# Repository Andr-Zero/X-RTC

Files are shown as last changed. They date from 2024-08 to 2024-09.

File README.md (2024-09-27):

# X-RTC
A supplemental Real Time Clock for the Original Xbox 

The Original Xbox does not keep time when unplugged for an extended period of time. While some homebew apps have NTP functionality built in, not everyone plugs the console into their home network every time they play. 

Designed so the battery is only used when AC power is removed from the console. A CR2032 in theory should last 6-10 years when constantly being used. 
Should work with any modchip and TSOPed consoles. Have not tested with BFM BIOSes. 

SDA\SDL from the console are also brought to a set of solder pads for ease of installation of any other mod that may require them. 



# Board Specifications
0.8mm thick, castellated holes on all sides.

# 1.0-1.4 Installation
On the bottom of the Xbox motherboard. If you have a pinheader already installed, remove excessive solder from the pins outlined in purple and any that would interfere with the installation of the X-RTC QSB. Install the QSB onto the LPC port as shown above, make sure the QSB is sitting flush against the board. While keeping the QSB aligned, solder the QSB to the LPC port and the ground point outlined in black. Run a short wire from the console's 3.3v standby outlined in red to the 3v3 StdBy pad on the QSB. Lastly wire a 3v battery to the Positive and Negative solder pads on the QSB.



# 1.6 Installation
On the bottom of the Xbox motherboard. Remove any existing LPC rebuild QSB or wires that maybe installed. If a pinheader is already installed, remove solder from the bottom of the pinheader. No need to remove the pinheader, just enough for the X-RTC QSB can sit flush against the board. Solder the various LAD points first, then the ground connections around the QSB, solder the QSB to the LPC port and pinheader last. Make sure the solder is connecting to the QSB, pinheader, and the main board. All the edge points on the QSB need to contact the board. Since the 1.6 consoles have it’s standby voltage on the LPC, no need to run a wire like the early revisions. Last step is wiring a 3v battery to the Positive and Negative solder pads on the QSB. Your install should look like the 1.6 install at the top of this README

# BOM

| Part | Description | Digikey Link |
| --- | --- | --- |
| `0.1 uF` | Generic 0.1uF Ceramic Cap | https://www.digikey.com/short/408q3vwn |
| `DS3231MZ` | I2C Real Time Clock | https://www.digikey.com/short/m05dd78z |
| `XC6206P332MR` | 3.3v Regulator for 1.6 ONLY | https://www.digikey.com/short/bqdqftzn |

# Software
Cerbios 2.4.0 or higher is required to use X-RTC. 

> ; Enables Automatic Time Sync With Optional RTC Hardware Connected to SMBus
> 
> RtcEnable = True

Using a Chip that can use PrometheOS:
Version 1.4.0 or higher is able to set the time, enable RTC in PrometheOS Settings. (Rebooting recommended) 

TSOP or Other:
Download the X-RTC.xbe into your Apps folder, within you can set the time. 

Once the time is set and Cerbios is configured. The time on the console will set automatically on boot.

# License, Credits, & Thanks
The hardware and it's related files is licensed under CERN-OHL-S v2 or later version.
See License.txt, cern_ohl_s_v2.txt, and cern_ohl_s_v2_user_guide.txt for details.

1.6 LPC rebuild portion by Kekule. -> https://github.com/Kekule-OXC/OXC_LPCorrectr

Team Resurgent for the idea, PrometheOS, and the XBE.

Cerbios team for including functionality into their BIOS.

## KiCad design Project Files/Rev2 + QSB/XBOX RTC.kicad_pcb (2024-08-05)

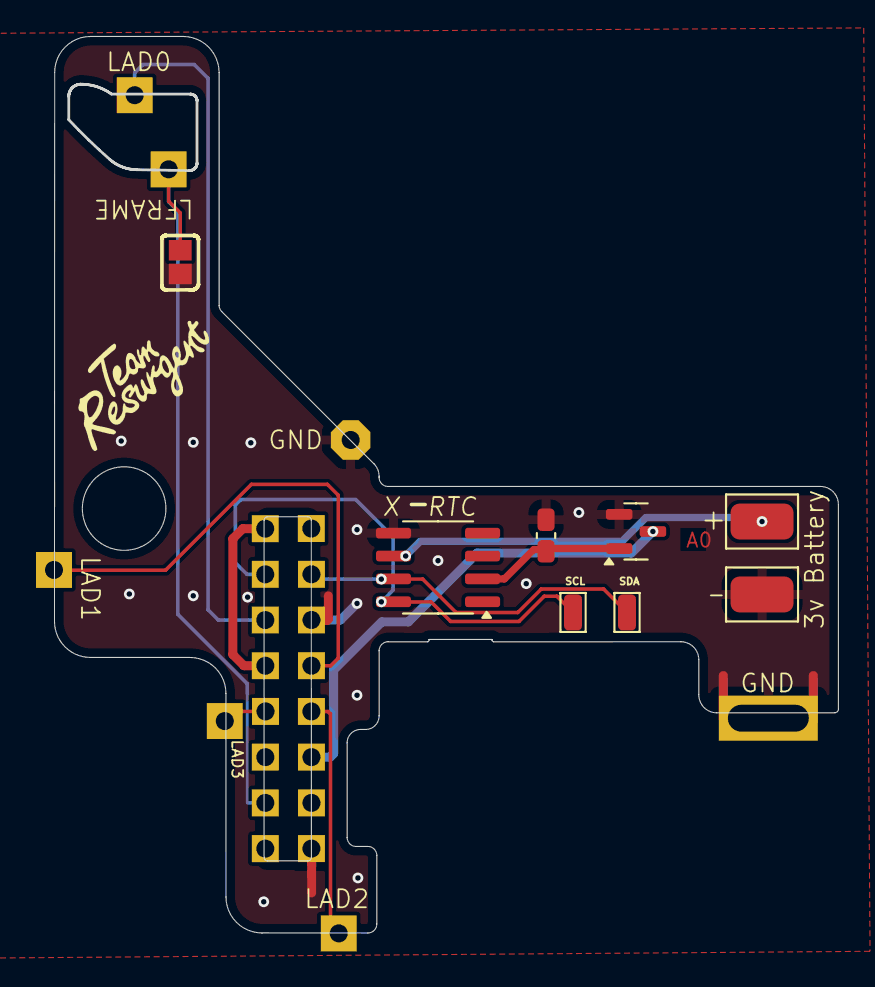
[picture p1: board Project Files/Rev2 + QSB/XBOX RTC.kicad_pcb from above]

Board: 2 copper layers, 43.6 x 49.8 mm, 7 parts (0 on the bottom side), 5 nets.

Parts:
C1: 0.1uF; C_0603_1608Metric
TP1: SCL; TestPoint_Pad_1.0x2.0mm
TP2: SDA; TestPoint_Pad_1.0x2.0mm
TP3: TestPoint; TestPoint_THTPad_2.5x2.5mm_Drill1.2mm
TP5: Batt +; TestPoint_Pad_1.0x2.0mm
TP6: Batt -; TestPoint_Pad_1.0x2.0mm
U1: DS3231MZ; SOIC-8_3.9x4.9mm_P1.27mm

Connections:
GND: C1.1, TP3.1, TP6.1, U1.5 (GND)
unnamed: TP1.1, U1.8 (SCL)
unnamed: TP2.1, U1.7 (SDA)
unnamed: TP5.1, U1.6 (VBAT)
unnamed: C1.2, U1.2 (VCC)

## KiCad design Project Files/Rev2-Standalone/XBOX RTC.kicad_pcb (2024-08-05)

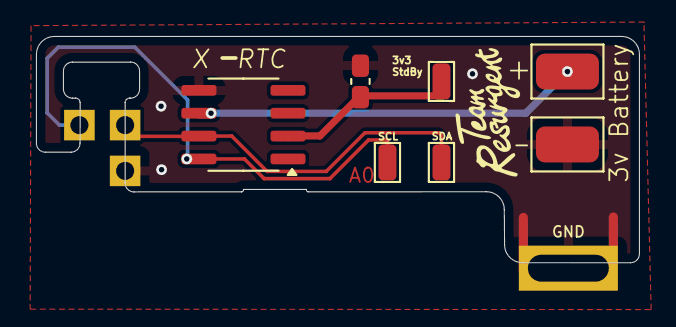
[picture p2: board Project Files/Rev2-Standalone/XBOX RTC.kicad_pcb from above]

Board: 2 copper layers, 33.5 x 12.6 mm, 9 parts (0 on the bottom side), 5 nets.

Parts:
C1: 0.1uF; C_0603_1608Metric
J3: Xbox LPC; PinSocket_2x08_P2.54mm_Vertical
TP1: SCL; TestPoint_Pad_1.0x2.0mm
TP2: SDA; TestPoint_Pad_1.0x2.0mm
TP3: TestPoint; TestPoint_THTPad_2.5x2.5mm_Drill1.2mm
TP4: 3v3 StdBy; TestPoint_Pad_1.0x2.0mm
TP5: Batt +; TestPoint_Pad_1.0x2.0mm
TP6: Batt -; TestPoint_Pad_1.0x2.0mm
U1: DS3231MZ; SOIC-8_3.9x4.9mm_P1.27mm

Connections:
GND: C1.1, J3.12, TP3.1, TP6.1, U1.5 (GND)
unnamed: J3.13, TP1.1, U1.8 (SCL)
unnamed: J3.14, TP2.1, U1.7 (SDA)
unnamed: TP5.1, U1.6 (VBAT)
unnamed: C1.2, TP4.1, U1.2 (VCC)

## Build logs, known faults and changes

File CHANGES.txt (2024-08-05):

July 28th 2024: Initial Release

August 4th 2024: Rerouted some traces for more continuous ground planes, increased LPC traces size to 0.2mm per feedback, removed mismatched silkscreen around ground points, moved the large GND pad .12mm as PCBWay suddenly had issues with it.

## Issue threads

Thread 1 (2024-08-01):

Add EDA design files

Redherring32, 2024-08-01:
The original self claimed intent of the OXC-LPCorrectr was to be open hardware.
Per the definition of open source the EDA software design files should be supplied. (E.g KiCad .kicad_pcb .kicad_sch and .kicad_pro files)
Gerber files are an output (they do not qualify for the definition of a source file, they're as close to source files as an EXE), and do not preserve the original documentation (schematic, editable layout, netlists, and net names) and therefore prevent anyone from contributing.

Admittedly the original project also doesn't properly do so either, but that doesn't stop this oversight from being corrected here. If you need any help with this just let me know.

Thanks.
-Red

MrMilenko, 2024-08-03:
When is MakeMHz going to release the KiCad files for the Xbox HD+ that they’ve been saying will be coming in the near future for the last 3 years?

Why is it that whenever someone outside of your group does anything, you guys flock to it with some kind of gotcha and make demands like this, but force pushing to fix two year old typos and releasing binary blobs as opensource is perfectly acceptable elsewhere?

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

hazardous774, 2024-08-03:
painschamp

Andr-Zero, 2024-08-05:
Alright... A couple musings, then I'm closing this.
1) To clarify the license, CERN-OHL-S v2 or later. The missing details in the readme and files needed to comply will be uploaded shortly with a revised gerbers, if not already.
2) One could argue comparing a gerber to a compiled executable is an error. They are indeed the source used for the production of a product. In a common format that most, if not all software can understand and import. In fact, this is how I imported Kekule's OXC-LPCorrectr into my project file. I often see other OSHW with only gerbers released.
3)Definition 1.8, " 'Complete Source' means the set of all Source necessary to Make a Product..." Since the PCB is a product, I see just the gerbers sufficient here.
4) In a partial contradiction of 3, yet partly affirming of 2 & 3. "...in the preferred form for making modifications..." What is “preferred”? Native EDA files? Well sure. For every EDA software out there? That seems silly… But that might be “preferred” by someone using a different EDA. Could just export as gerbers as that almost universal. Again, that’s how I imported the existing OXC-LPCorrectr design. However, that’s far from ideal for a much more complex design. I say “Preferred” is too ambiguous…
5) @MrMilenko, seeing that years ago is why I bought several in support of the designer. Seeing how nothing came from that I do feel taken advantage of, now regret that decision.

Regardless if my musings are accurate or not. It’s late at night and I really care either way. I will release the KiCAD files I have, I feel that is in the spirt of being Open Sourced. I think I took all the none related information out, like my grocery list from a few weeks ago… There are no schematics, as there was not a need for one. Otherwise I would include those as well. To the best of my current sleep deprived state, I believe I have all the necessary things in place for the OSHW license. If not, please contact my directly if you so feel.

Closed 2024-08-05.

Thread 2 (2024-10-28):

CR2032 situation

Radeon91, 2024-10-28:
Hi, could be possible to enlarge the pcb to add a holder for cr2032 or anotther small battery

Andr-Zero, 2024-10-30:
Question is where to put it. There isn't really much room where the board is now without worries hitting the IO Shield or other components on the main board across revisions. I did not want to top mount as I knew people likely already had a pinheader installed and removing it to install this did not make sense. Considered a seperate board elsewhere to hold a CR2032, then came the questions of where would people like it most and connecting the two. I knew despite what I came up with, someone somewhere was not going to like it. Plus it would also increase the price of materials, the RTC IC is already kinda expensive... Sooo, I decided to just do the solder pads instead to let people come up with their own solutions.

Some people sent me great pics of their installs! There's a Lillypad CR2032 holder that fits beside the IDE connector on the top side of the board, almost looks like it was made to go there, just held down with some foam tape. Saw someone use 18650s mounted above the AV port in a 3D printed bracket thingy. Someone else had a ton of CR2477 with tabs and used those instead.

Personally I'm going to get some Lillypad CR2032 holders and see how it looks mounted on the IO shield near the top. So if you ever had to replace the battery it's just right there. Though a standard CR2032 should expire from age before being drained from power consumption. So not sure how important that would be.

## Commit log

2024-07-31 Added App to set the time on the X-RTC board.
2024-08-05 Add files via upload
    Rerouted some traces to allow for better continuous ground planes, Increased the LPC traces to 0.2mm per some various feedback, removed mismatched silkscreens from ground points, added license on back silkscreen, PCBWay suddenly had issues with a tolerance on the large ground pad, so moved it 0.07mm to appease them.
2024-08-05 Add files via upload
    Initial upload of KiCAD files.
    [XBOX RTC.kicad_pcb]
2024-08-05 Add files via upload
    Did not mean to removed the older gerber files...

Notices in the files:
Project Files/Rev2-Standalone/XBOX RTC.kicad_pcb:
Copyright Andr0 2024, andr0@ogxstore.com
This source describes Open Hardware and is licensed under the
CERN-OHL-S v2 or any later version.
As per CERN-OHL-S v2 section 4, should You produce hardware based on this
